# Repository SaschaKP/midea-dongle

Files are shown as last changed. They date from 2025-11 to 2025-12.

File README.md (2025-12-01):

# Midea WiFi Dongle - v3

This repo is a complete rework of [Rene Klootwijk's repository](https://github.com/reneklootwijk/mideahvac-dongle). So credits for the initial hardware study and design go to him!

I've made a lot of changes to the board:
* the board will fit inside the original spacer, occuping the original space, but without casing
* all pads can be soldered with hot-air gun and soldering paste, they are slightly larger for that purpose in mind
* it uses an ESP32 C6 and the software for making it work with this dongle (esphome) can be found [in my repository](https://github.com/SaschaKP/esphome-midea-direct)
* Converted the KiCad project to KiCad 9

For this particular repository you can use an ESP32 C6 MINI (WT0132C6-S5) that can be used as a drop-in replacement for ESP-12F

That's what the board now looks like:
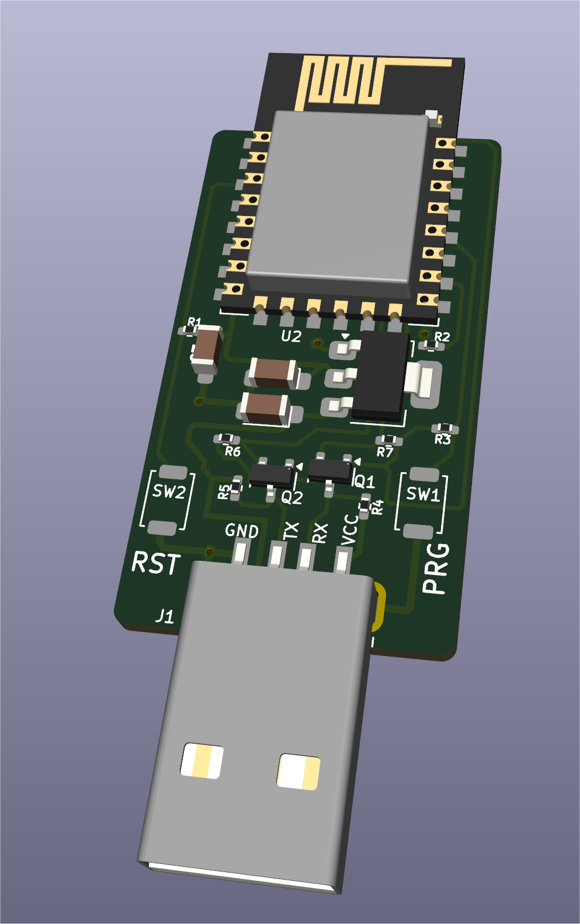
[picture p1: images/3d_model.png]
How it looks

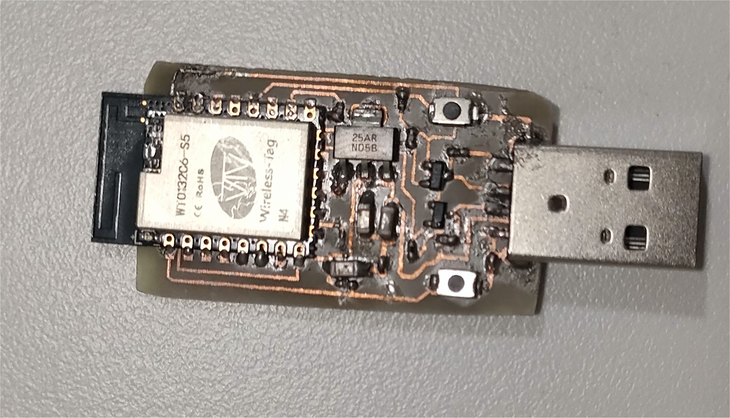
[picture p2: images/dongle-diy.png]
Real Object DIY


## PCB and Parts
* The buttons are 3x4mm in size. Height is up to your liking. Can easily be found on AliExpress:
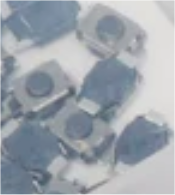
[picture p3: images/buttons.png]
Buttons

* Specs of the USB jack, can also be found on AliExpress:
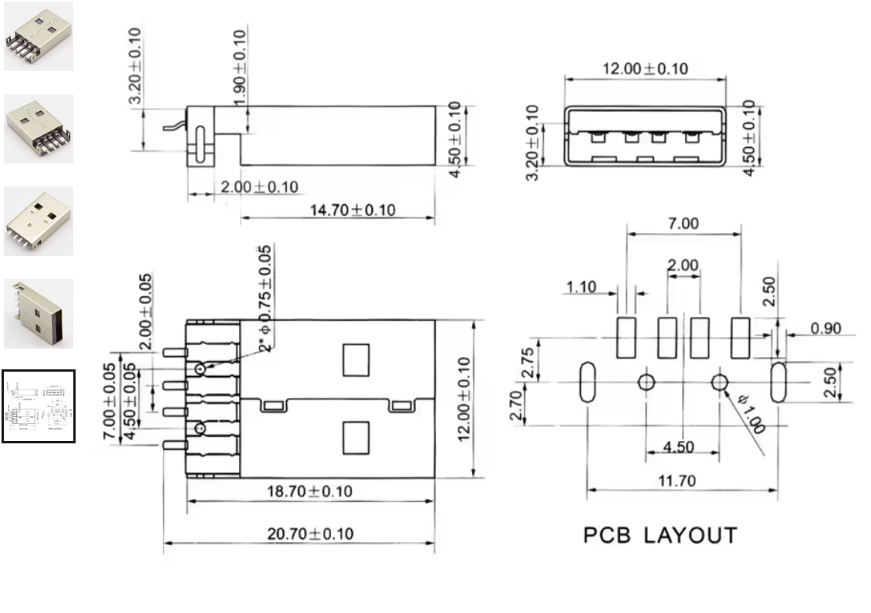
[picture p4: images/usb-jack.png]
USB Jack

* LDO Caps (C1 & C2) can be either tantalum or ceramic: Officially should be tantalum, but ceramic work just fine. 
* Remember that the WT0132C6-S5 (ESP32 C6 MINI) is interchangeable with ESP-12F or ESP-07 which offers an external antenna:
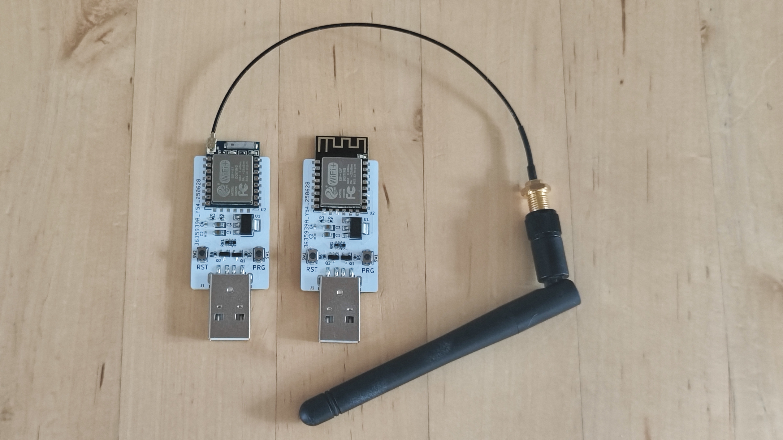
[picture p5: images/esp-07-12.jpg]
Boards with ESP-07 and ESP-12F


I **highly** recommend taking a look at the iBOM file that can also be found in the "production-files" folder. It makes sourcing the parts and soldering so much easier!

## Making of PCB
You will find some files to print for classic paper-toner-iron transfer on copper for etching, or you can also use a more modern approach with a 3D printer (with 0.25 or less nozzle) with spray painting or top of the model to track the negative part, etching as usual with acid and subsequent protective paint upon tracks to avoid potential short circuits later.
If you are familiar with this kind of prototyping you will find what you need inside the print_file directory
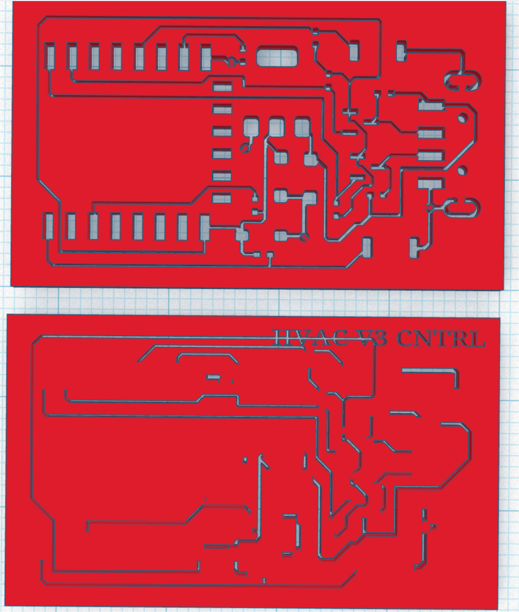
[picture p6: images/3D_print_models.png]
3D models for etching and protective layer


## Flashing
Flashing the ESP can be done using any USB-to-UART adapter. I recommend getting an USB-A-socket cable with open ends, so you can crimp a dupont at the open end.
So TX from the dongle goes to RX on the UART adapter and RX from the dongle goes to TX on the UART adapter. Set the UART adapter to 5V. Yes, it is safe. You will **not** burn the ESP in this case! The board has two mosfets that will switch the pins to 3v3.
Now how to actually flash the board:
 1. Create a new device under "ESPHome Builder" in Home Assistant. Choose `ESP32 C6 devkitm` as board
 2. You can find an example config under "esphome". Edit the config in ESPHome builder and substitute the placeholders and potentially the board.
 3. Install and download.
 4. Now open [ESPHome Web](https://web.esphome.io)
 5. Connect the UART adapter to your PC, but not the dongle just yet!
 6. Hold the "PRG" button on the dongle and keep holding it!
 7. Now connect the dongle to the UART adapter.
 8. Click "Connect" on ESPHome Web, select the UART adapter, click "Install", select the bin you've just built and downloaded and flash it.
 9. As soon as it says "Erasing" or "Flashing", you can release the "PRG" button.
 10. Wait  for it to be installed and it will show up in your Wi-Fi and under "Devices" in Home Assistant

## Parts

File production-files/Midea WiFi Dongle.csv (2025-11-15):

Id | Riferimento | Impronta | Quantità | Valore | Produttore
1 | U2 | WT0132C6-S5 | 1 | WT0132C6-S5
2 | C1,C2 | CP_1.62x0.84mm_0603_1608metric_HandSolder | 2 | 22uF
3 | U1 | SOT-223 | 1 | AMS1117-3.3
4 | R2,R5,R6,R8,R1,R4,R7,R3 | R_0402_1005Metric_Pad0.72x0.64mm_HandSolder | 8 | 10k
5 | Q2,Q1 | SOT-23 | 2 | BSS138
6 | J1 | USB_A_CNCTech_1001-011-01101_Horizontal | 1 | USB_A
7 | SW2,SW1 | SW_Push_SPST_NO_Alps_SKRK | 2 | SW_Push
8 | C3 | CP_1.62x0.84mm_0603_1608Metric | 1 | 100nF

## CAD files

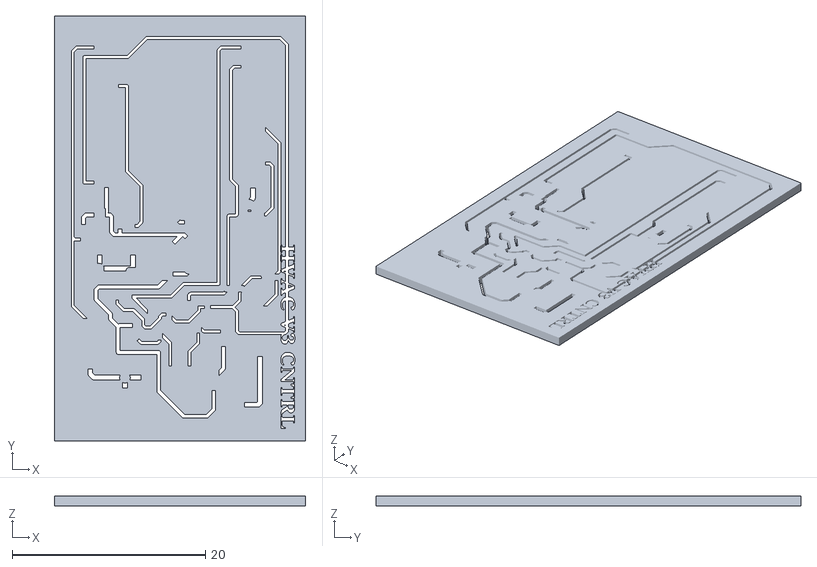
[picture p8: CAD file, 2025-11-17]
print_file/3D_midea_dongle_tracks_coating.stl
26.0 x 44.0 x 1.00

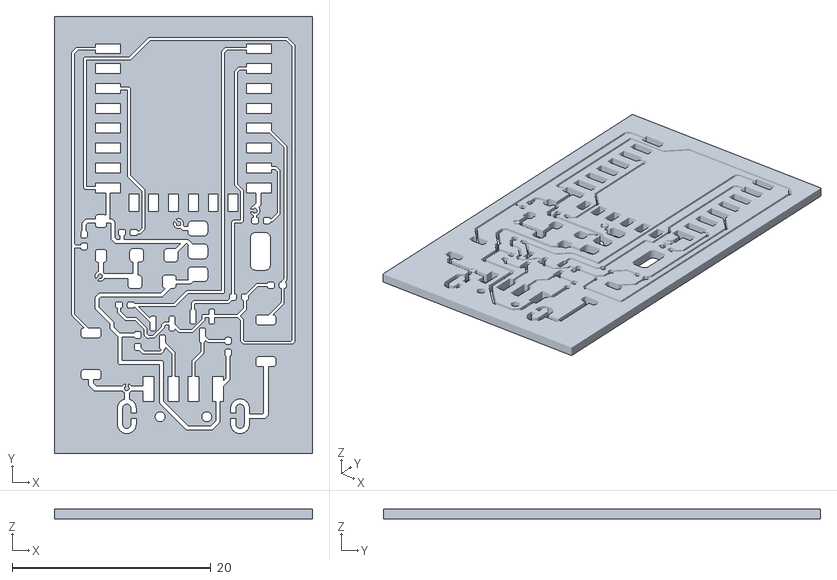
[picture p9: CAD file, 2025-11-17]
print_file/3D_midea-dongle_tracks (250micron print).stl
26.0 x 44.0 x 1.00

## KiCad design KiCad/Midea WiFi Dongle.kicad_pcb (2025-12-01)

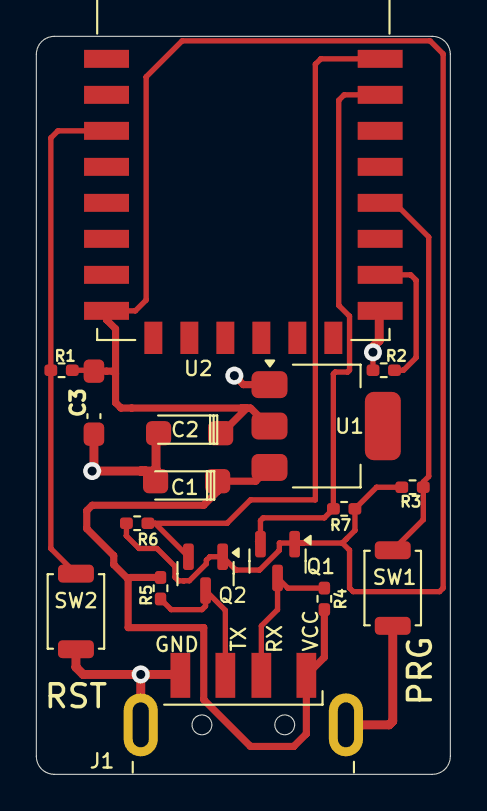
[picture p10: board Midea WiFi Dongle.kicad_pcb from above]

Board: 2 copper layers, 23.0 x 41.0 mm, 18 parts (1 on the bottom side), 10 nets.

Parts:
C1, C2: 22uF; CP_1.62x0.84mm_0603_1608metric_HandSolder
C3: 100nF; CP_1.62x0.84mm_0603_1608Metric
G1: LOGO; Yoshi-Egg-Small
J1: USB_A; USB_A_CNCTech_1001-011-01101_Horizontal
Q1, Q2: BSS138; SOT-23
R1, R2, R3, R4, R5, R6, R7: 10k; R_0402_1005Metric_Pad0.72x0.64mm_HandSolder
SW1, SW2: SW_Push; SW_Push_SPST_NO_Alps_SKRK
U1: AMS1117-3.3; SOT-223
U2: WT0132C6-S5

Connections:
+3V3: C2.1, C3.2, Q1.1 (G), Q2.1 (G), R1.2, R3.2, R6.2, R7.1, U1.2 (VO), U2.8 (VCC)
+5V: C1.1, J1.1 (VBUS), R4.2, R5.1, U1.3 (VI)
/EN: R1.1, SW2.2, U2.3 (EN)
/GPIO7: R2.1, U2.16 (GPIO7)
/GPIO9: R3.1, SW1.2, U2.18 (GPIO9)
/RN1-5: Q2.2 (S), R6.1, U2.22 (GPIO16/TXD)
/RN1-6: Q1.2 (S), R7.2, U2.21 (GPIO17/RXD)
/RX_USB: J1.2 (D-), Q1.3 (D), R4.1
/TX_USB: J1.3 (D+), Q2.3 (D), R5.2
GND: C1.2, C2.2, C3.1, J1.4 (GND), J1.5 (Shield), R2.2, SW1.1, SW2.1, U1.1 (GND), U2.15 (GND)

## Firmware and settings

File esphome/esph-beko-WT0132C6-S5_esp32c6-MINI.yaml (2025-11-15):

substitutions:
  name: "clima-home"
  friendly_name: "Clima Home"
  idname: clima_home

esphome:
  name: $name
  friendly_name: $friendly_name
  name_add_mac_suffix: False

esp32:
  board: esp32-c6-devkitc-1
  partitions: common/esphome/partitions_zb.csv
  framework: 
    type: esp-idf

preferences:
  flash_write_interval: 
    seconds: 120

# Enable logging
logger:
  baud_rate: 0
  level: DEBUG

# Enable Home Assistant API
api:
  encryption:
    key: !secret api
  reboot_timeout: 0s

ota:
  - platform: esphome
    password: !secret ota

zigbee:
  id: "zb"
  router: true
  power_supply: 1
  on_join:
    then:
      - logger.log: "Joined network"

wifi:
  enable_btm: true
  enable_rrm: true
  ssid: !secret wifi_ssid
  password: !secret wifi_password
  reboot_timeout: 3min

button:
  - platform: restart
    name: "Restart"
    id: button_restart

external_components:
  - source: github://luar123/zigbee_esphome
    components: [zigbee]
    refresh: 0s
  - source: github://SaschaKP/esphome-midea-direct
    refresh: 0s

zigbee:
  id: "zb"
  router: true
  power_supply: 1
  components: none
  on_join:
    then:
      - logger.log: "Joined network"

binary_sensor:
  - platform: gpio
    name: ZigBee Btn
    pin:
      number: 9
      mode:
        input: true
        pullup: true
      inverted: True
    id: button_1
    on_press:
      then:
        - zigbee.report: zb
    on_click:
      min_length: 10s
      max_length: 30s
      then:
        - zigbee.reset: zb

uart:
  id: uart_1
  baud_rate: 9600
  tx_pin: GPIO16
  rx_pin: GPIO17

climate:
  - platform: midea_direct
    id: $idname   # Use a unique id
    name: $friendly_name          # Use a unique name
    beeper: True
    autoconf: False
    period: 4s
    timeout: 3s                       # Optional
    num_attempts: 1              # Optional
    visual:                              # Optional
      min_temperature: 17 °C    # min: 17
      max_temperature: 30 °C    # max: 30
      temperature_step: 1 °C  # min: 0.5
    supported_modes:            # Optional. All capabilities in this section may be detected by autoconf.
      - HEAT_COOL
      - COOL
      - HEAT
      - DRY
      - FAN_ONLY
    custom_fan_modes:
      - SILENT
      - TURBO
    supported_presets:          # Optional. All capabilities in this section may be detected by autoconf.
      - BOOST
      - SLEEP
    custom_presets:             # Optional. All capabilities in this section may be detected by autoconf.
      - FREEZE_PROTECTION
    supported_swing_modes: # All capabilities in this section detected by autoconf.
      - VERTICAL

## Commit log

2025-11-17 Added BMP (for traditional, toner, paper, iron method) and STL (negative, for 3D printer method, with spray paint, requires 0.25mm nozzle)
    [3D_midea-dongle_tracks (250micron print).stl, Midea WiFi Dongle.kicad_pcb]
2025-11-17 add holes for usb jack
    [3D_midea-dongle_tracks (250micron print).stl]
2025-11-17 Adding 3D print file for tracks coating/protective layer
    [3D_midea_dongle_tracks_coating.stl]
2025-12-01 updated 3D model, I have to update the 3D printing model too.
    [Midea WiFi Dongle.kicad_pcb, Midea WiFi Dongle.kicad_sch]
